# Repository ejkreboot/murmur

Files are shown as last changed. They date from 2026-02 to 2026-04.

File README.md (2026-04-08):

# Murmur

An audio "casette" player for the 21st century.

---

## Philosophy

Most audio hardware today is optimized for connectivity. Bluetooth, WiFi, cloud sync, firmware updates, pairing modes, app dependencies. These features solve real problems, but they also introduce friction — dead batteries from background radios, pairing failures at the worst moments, apps that require accounts, devices that stop working when servers go away, constant distractions and potentials for invasion of privacy or other undesirable intrusions.

Murmur is a deliberate step in the other direction. It plays audio files from a microSD card through a 3.5mm jack. That's the whole product. No wireless radios in use, no companion app, no account required. You put files on a card and press play.

Future revisions may (or may not) add internet and bluetooth features if they "just work" and maintain the Murmur ethos. 

The name comes from the idea that good audio gear should be unobtrusive. It should murmur in the background of your life, not demand attention.

---

## Hardware

**Microcontroller:** ESP32-S3-WROOM-1U (8MB flash)  
**DAC / Headphone driver:** Texas Instruments TAD5242  
**Battery management:** Microchip MCP73871  
**Storage:** MicroSD (via USB-C when connected to a computer)  
**Motion sensor:** ST LIS3DH (3-axis accelerometer)  
**Charging / Data:** USB-C  
**Output:** 3.5mm stereo headphone jack (PJ-327C-4A)

The ESP32-S3 was chosen for its capable USB peripheral support and audio I2S interface, not its wireless features. The TAD5242 handles D/A conversion and drives headphones directly. The MCP73871 manages single-cell Li-Ion/LiPo charging with thermistor-based temperature protection.

---

## User's Manual

For features, usage instructions, button controls, and audiobook support, see the **[Murmur User's Manual](https://ejkreboot.github.io/murmur/murmur_manual.html)**.

---

## Repository Contents

```
BOM.csv          — Full bill of materials with JLCPCB part numbers
docs/            — User's manual and supporting images
gerbers/         — Fabrication files (Gerber + drill) ready for PCB manufacture
firmware/murmur/ — Arduino sketch and source for the ESP32-S3
firmware/tools/  — Utilities (logo bitmap converter)
images/          — PCB renders, schematics, logos, and 3D model
Models/          — 3D-printable enclosure and button cap files (.3mf, .step)
```

---

## Firmware

The firmware lives in `firmware/murmur/` and is an Arduino sketch targeting the **ESP32-S3-WROOM-1U**. It uses the [Arduino AudioTools](https://github.com/pschatzmann/arduino-audio-tools) library with the Helix MP3 decoder.

### Building

1. Install the [Arduino IDE](https://www.arduino.cc/en/software) (or PlatformIO) with ESP32-S3 board support.
2. Install the required libraries: **Arduino AudioTools**, **Adafruit SSD1306**, **Adafruit LIS3DH**.
3. Open `firmware/murmur/murmur.ino`.
4. Select the **ESP32S3 Dev Module** board and configure: 8 MB flash, USB CDC on boot enabled.
5. Upload.

### Architecture

The firmware is modular and class-based:

| Module | Responsibility |
|---|---|
| `murmur.ino` | App state machine, NVS persistence, sleep/wake, main loop |
| `AudioPlayer` | MP3 decode, I2S output, EQ, volume, track/folder navigation |
| `ButtonManager` | 5-button debounce FSM with tap-defer and long-press detection |
| `DisplayManager` | OLED screens: track, settings menu, playlist, chapters, battery |
| `AccelManager` | LIS3DH flat-detect for display sleep/wake |
| `ID3Parser` | ID3v2 tag parsing: genre, chapters, MP3 frame header |
| `config.h` | Pin definitions, mode enums, tuning constants |

---

## Building One

The gerbers are in `gerbers/` and the BOM references JLCPCB part numbers, so ordering a board through JLCPCB (or any compatible fab) should be straightforward. The BOM includes all SMD components; assembly is possible by hand but a stencil is recommended given the QFN and LGA packages.

3D-printable enclosure and button cap models are in `Models/`.

---

## Contributing

This project is open source under the CERN-OHL-S-2.0 license. Improvements and modifications encouraged. Issues and pull requests are welcome.

---

## License

CERN-OHL-S-2.0

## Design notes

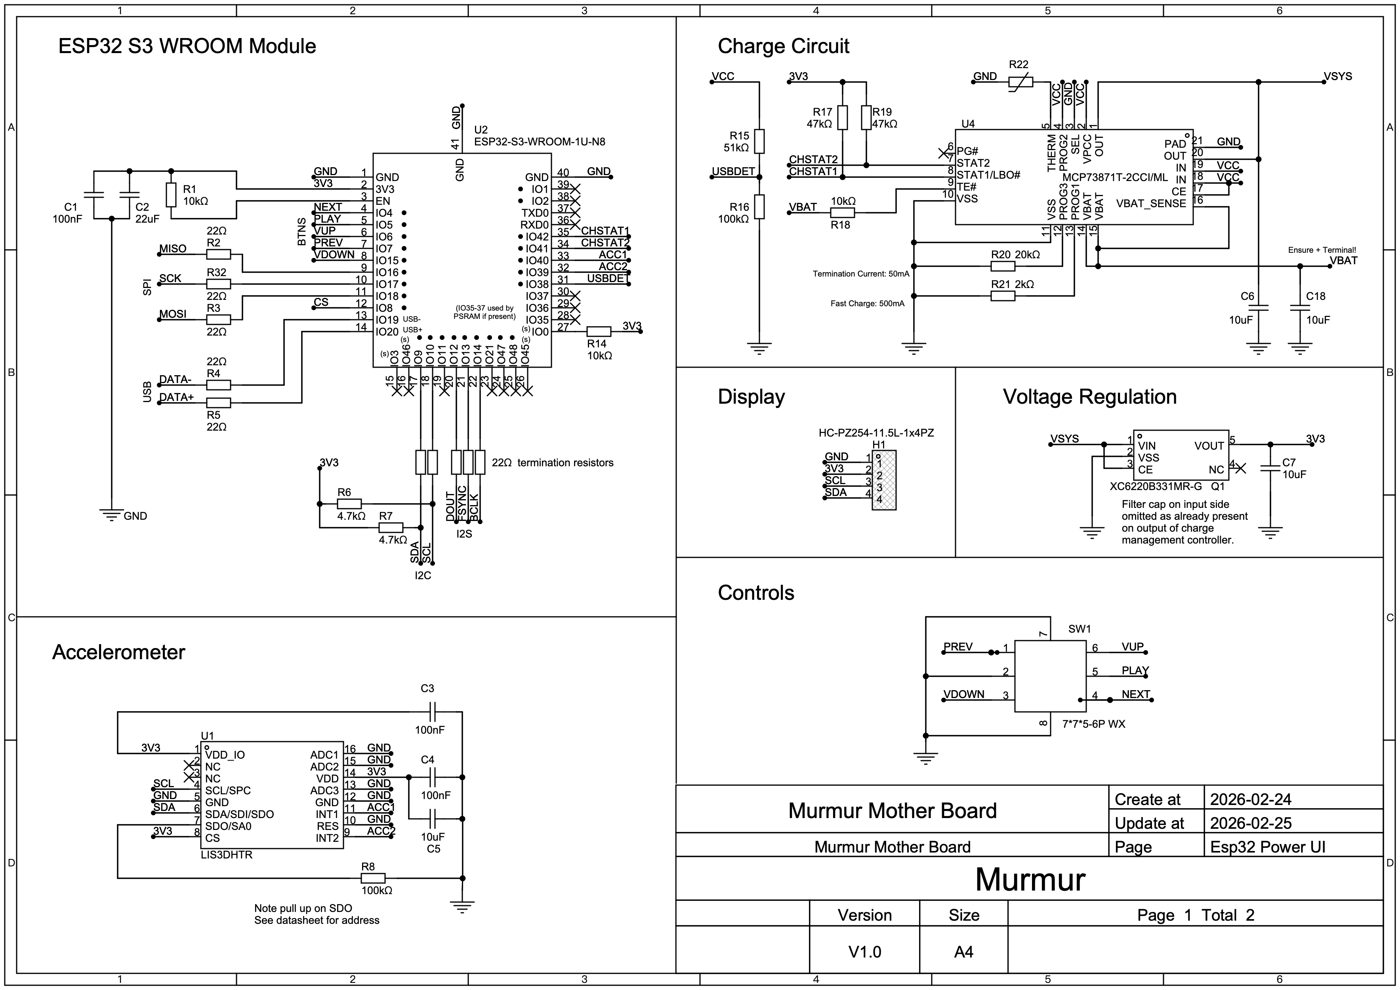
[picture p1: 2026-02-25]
images/SCH_Murmur Mother Board_1-Esp32 Power UI_2026-02-25.png

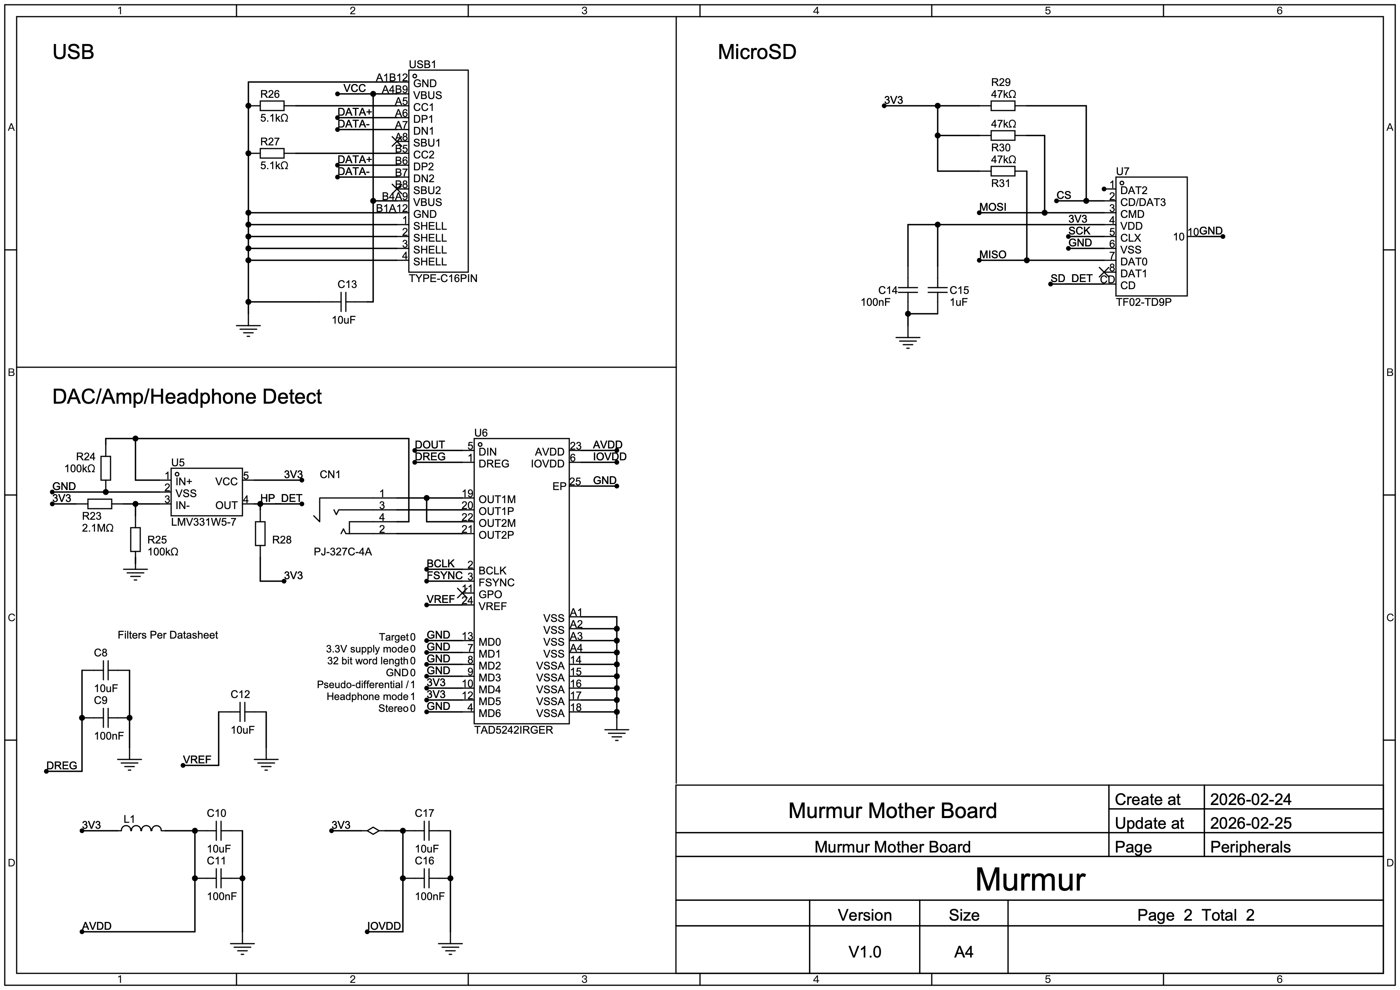
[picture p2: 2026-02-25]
images/SCH_Murmur Mother Board_2-Peripherals_2026-02-25.png

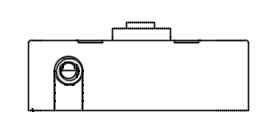
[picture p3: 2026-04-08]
docs/images/Drawing1.png

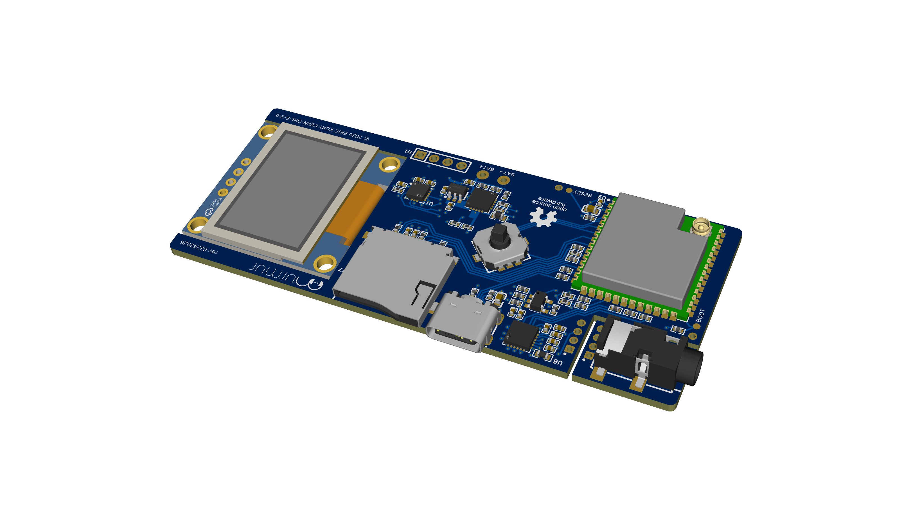
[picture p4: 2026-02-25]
images/PCB_3D.png

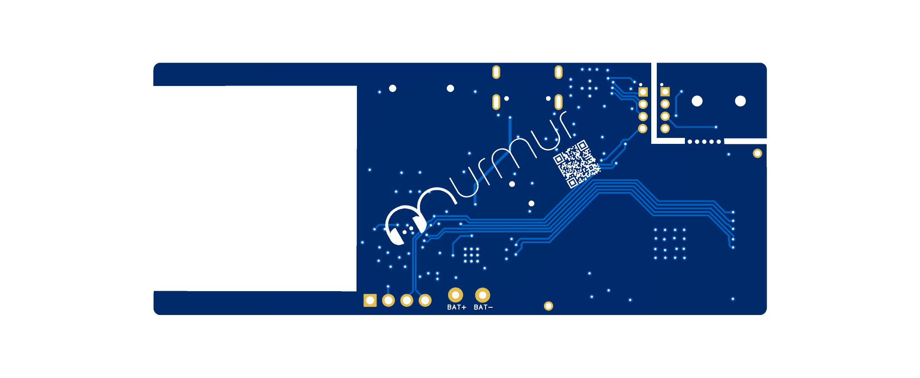
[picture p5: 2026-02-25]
images/PCB_2D_bottom.png

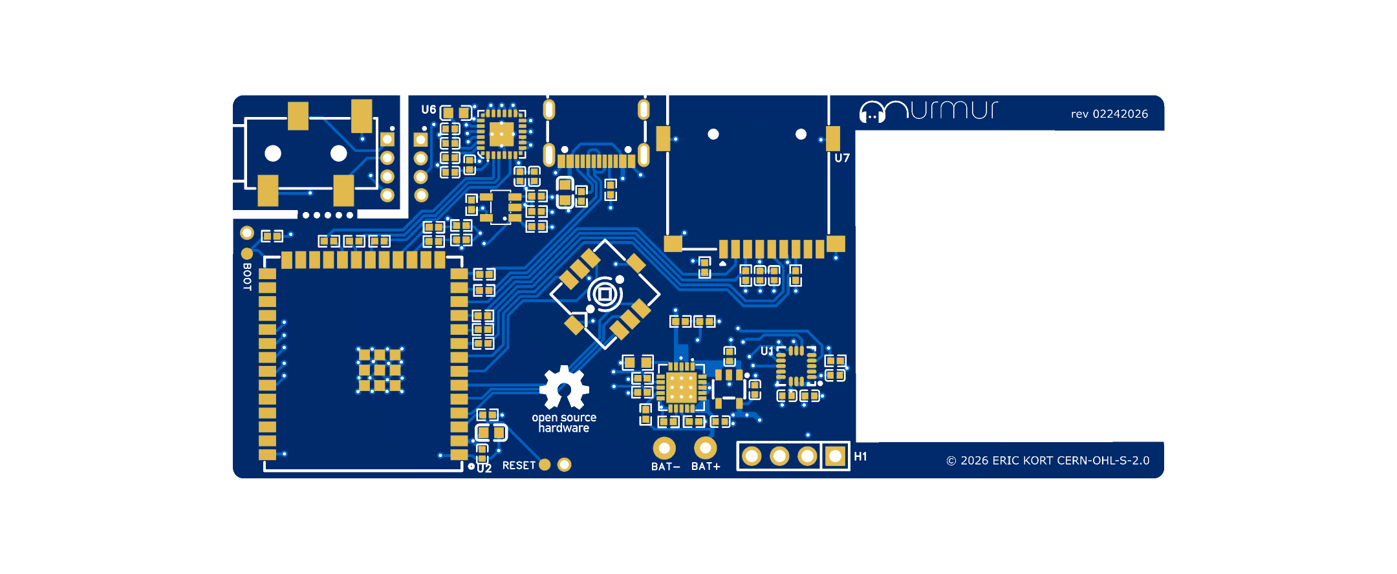
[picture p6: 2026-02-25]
images/PCB_2D_top.png

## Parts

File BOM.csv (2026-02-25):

No. | Quantity | Comment | Designator | Footprint | Value | Manufacturer Part | Manufacturer | Supplier Part | Name | Device | JLCPCB Price | Primary Category | Secondary Category | Datasheet
1 | 7 | 100nF | C1,C3,C4,C9,C11,C14,C16 | C0402 | 100nF | CL05B104KO5NNNC | SAMSUNG(三星) | C1525 | 100nF | CL05B104KO5NNNC | 0.0002 |  |  | https://item.szlcsc.com/datasheet/CL05B104KO5NNNC/1877.html
2 | 1 | 22uF | C2 | C0603 | 22uF | CL10A226MQ8NRNC | SAMSUNG(三星) | C59461 | 22uF | CL10A226MQ8NRNC | 0.0014 |  |  | https://item.szlcsc.com/datasheet/CL10A226MQ8NRNC/60514.html
3 | 8 | 10uF | C5,C6,C7,C8,C10,C12,C17,C18 | C0402 | 10uF | CL05A106MQ5NUNC | SAMSUNG(三星) | C15525 | 10uF | CL05A106MQ5NUNC | 0.0009 |  |  | https://item.szlcsc.com/datasheet/CL05A106MQ5NUNC/16204.html
4 | 1 | 10uF | C13 | C0603 | 10uF | CL10A106MA8NRNC | SAMSUNG(三星) | C96446 | 10uF | CL10A106MA8NRNC | 0.0026 |  |  | https://item.szlcsc.com/datasheet/CL10A106MA8NRNC/97651.html
5 | 1 | 1uF | C15 | C0402 | 1uF | CL05A105KA5NQNC | SAMSUNG(三星) | C52923 | 1uF | CL05A105KA5NQNC | 0.0005 | Capacitors | Multilayer Ceramic Capacitors MLCC - SMD/SMT | https://item.szlcsc.com/datasheet/CL05A105KA5NQNC/53938.html
6 | 1 | PJ-327C-4A | CN1 | AUDIO-SMD_PJ-327C-4A |  | PJ-327C-4A | 韩国韩荣 | C145813 | PJ-327C-4A | PJ-327C-4A | 0.0207 |  |  | https://item.szlcsc.com/datasheet/PJ-327C-4A/157145.html
7 | 1 | GZ1608D601TF | L1 | L0603 |  | GZ1608D601TF | Sunlord(顺络) | C1002 | GZ1608D601TF | GZ1608D601TF | 0.0019 | Filters | Ferrite Beads | https://item.szlcsc.com/datasheet/GZ1608D601TF/1354.html
8 | 1 | XC6220B331MR-G | Q1 | SOT-25_L3.0-W1.6-P0.95-LS2.8-TL |  | XC6220B331MR-G | TOREX(特瑞仕) | C86534 | XC6220B331MR-G | XC6220B331MR-G | 0.0699 |  |  | https://item.szlcsc.com/datasheet/XC6220B331MR-G/87711.html
9 | 3 | 10kΩ | R1,R14,R18 | R0402 | 10kΩ | 0402WGF1002TCE | UNI-ROYAL(厚声) | C25744 | 10kΩ | 0402WGF1002TCE | 0.0002 |  |  | https://item.szlcsc.com/datasheet/0402WGF1002TCE/26487.html
10 | 10 | 22Ω | R2,R3,R4,R5,R9,R10,R11,R12,R13,R32 | R0402 | 22Ω | 0402WGF220JTCE | UNI-ROYAL(厚声) | C25092 | 22Ω | 0402WGF220JTCE | 0.0002 |  |  | https://atta.szlcsc.com/upload/public/pdf/source/20200306/C422600_1E6D84923E4A46A82E41ADD87F860B5C.pdf
11 | 2 | 4.7kΩ | R6,R7 | R0402 | 4.7kΩ | 0402WGF4701TCE | UNI-ROYAL(厚声) | C25900 | 4.7kΩ | 0402WGF4701TCE | 0.0002 |  |  | https://item.szlcsc.com/datasheet/0402WGF4701TCE/26643.html
12 | 5 | 100kΩ | R8,R16,R24,R25,R28 | R0402 | 100kΩ | 0402WGF1003TCE | UNI-ROYAL(厚声) | C25741 | 100kΩ | 0402WGF1003TCE | 0.0002 |  |  | https://atta.szlcsc.com/upload/public/pdf/source/20180314/0E2614623E0414D50D3004040B0D85FE.pdf,https://item.szlcsc.com/datasheet/0402WGF1003TCE/26484.html
13 | 1 | 51kΩ | R15 | R0402 | 51kΩ | 0402WGF5102TCE | UNI-ROYAL(厚声) | C25794 | 51kΩ | 0402WGF5102TCE | 0.0002 |  |  | https://atta.szlcsc.com/upload/public/pdf/source/20200306/C422600_1E6D84923E4A46A82E41ADD87F860B5C.pdf
14 | 5 | 47kΩ | R17,R19,R29,R30,R31 | R0402 | 47kΩ | 0402WGF4702TCE | UNI-ROYAL(厚声) | C25792 | 47kΩ | 0402WGF4702TCE | 0.0002 |  |  | https://item.szlcsc.com/datasheet/0402WGF4702TCE/26535.html
15 | 1 | 20kΩ | R20 | R0402 | 20kΩ | 0402WGF2002TCE | UNI-ROYAL(厚声) | C25765 | 20kΩ | 0402WGF2002TCE | 0.0002 |  |  | https://atta.szlcsc.com/upload/public/pdf/source/20200306/C422600_1E6D84923E4A46A82E41ADD87F860B5C.pdf
16 | 1 | 2kΩ | R21 | R0402 | 2kΩ | 0402WGF2001TCE | UNI-ROYAL(厚声) | C4109 | 2kΩ | 0402WGF2001TCE | 0.0002 |  |  | https://atta.szlcsc.com/upload/public/pdf/source/20200306/C422600_1E6D84923E4A46A82E41ADD87F860B5C.pdf
17 | 1 | KNTC0603/10KJ3950 | R22 | R0603 |  | KNTC0603/10KJ3950 | KUU | C20612968 | KNTC0603/10KJ3950 | KNTC0603/10KJ3950 | 0.0035 | Sensors | NTC Thermistors | https://item.szlcsc.com/datasheet/KNTC0603%252F10KJ3950/21973016.html
18 | 1 | 2.1MΩ | R23 | R0402 | 2.1MΩ | RC0402FR-072M1L | YAGEO(国巨) | C477638 | 2.1MΩ | RC0402FR-072M1L | 0.0001 |  |  | https://atta.szlcsc.com/upload/public/pdf/source/20200715/C477638_CABFCAEDA01CE96BF50AD84070FAC134.pdf
19 | 2 | 5.1kΩ | R26,R27 | R0402 | 5.1kΩ | 0402WGF5101TCE | UNI-ROYAL(厚声) | C25905 | 5.1kΩ | 0402WGF5101TCE | 0.0002 |  |  | https://item.szlcsc.com/datasheet/0402WGF5101TCE/26648.html
20 | 1 | 7*7*5-6P WX | SW1 | SW-SMD_6P-L7.0-W7.0-P1.40-LS7.4-TL |  | 7*7*5-6P WX | SHOU HAN(首韩) | C2858286 | 7*7*5-6P WX | 7*7*5-6P WX | 0.0424 |  |  | https://atta.szlcsc.com/upload/public/pdf/source/20210806/C2858286_484786EF684589807E899A8060F52B6F.pdf
21 | 1 | LIS3DHTR | U1 | LGA-16_L3.0-W3.0-P0.50-TL |  | LIS3DHTR | ST(意法半导体) | C15134 | LIS3DHTR | LIS3DHTR | 0.115 | Sensors | Accelerometers | https://item.szlcsc.com/datasheet/LIS3DHTR/15808.html
22 | 1 | ESP32-S3-WROOM-1U-N8 | U2 | WIRELM-SMD_ESP32-S3-WROOM-1U |  | ESP32-S3-WROOM-1U-N8 | ESPRESSIF(乐鑫) | C2980297 | ESP32-S3-WROOM-1U-N8 | ESP32-S3-WROOM-1U-N8 | 0.726 | IoT/Communication Modules | WiFi Modules | https://item.szlcsc.com/datasheet/ESP32-S3-WROOM-1U-N8/3401549.html
23 | 1 | MCP73871T-2CCI/ML | U4 | QFN-20_L4.0-W4.0-P0.5-BL-EP |  | MCP73871T-2CCI/ML | MICROCHIP(美国微芯) | C511310 | MCP73871T-2CCI/ML | MCP73871T-2CCI/ML | 0.306 | Power Management (PMIC) | Battery Management | https://item.szlcsc.com/datasheet/MCP73871T-2CCI%252FML/525757.html
24 | 1 | LMV331W5-7 | U5 | SOT-23-5_L3.0-W1.7-P0.95-LS2.8-BR |  | LMV331W5-7 | DIODES(美台) | C107643 | LMV331W5-7 | LMV331W5-7 | 0.0172 | Amplifiers/Comparators | Comparators | https://item.szlcsc.com/datasheet/LMV331W5-7/108862.html
25 | 1 | TAD5242IRGER | U6 | VQFN-24_L4.0-W4.0-P0.50-TL_RGE0024R |  | TAD5242IRGER | TI(德州仪器) | C42414591 | TAD5242IRGER | TAD5242IRGER_C42414591 | 0.9899 | Interface | Audio Interface ICs | https://item.szlcsc.com/datasheet/TAD5242IRGER/44407216.html
26 | 1 | TF02-TD9P | U7 | CONN-SMD_TF02-TD9P |  | TF02-TD9P | BXCONN(宝讯) | C36936583 | TF02-TD9P | TF02-TD9P | 0.014 |  |  | https://item.szlcsc.com/datasheet/TF02-TD9P/38663659.html
27 | 1 | TYPE-C16PIN | USB1 | USB-C-SMD_TYPE-C16PIN |  | TYPE-C16PIN | SHOU HAN(首韩) | C393939 | TYPE-C16PIN | TYPE-C16PIN | 0.0103 | Connectors | USB Connectors | https://item.szlcsc.com/datasheet/TYPE-C16PIN/372551.html

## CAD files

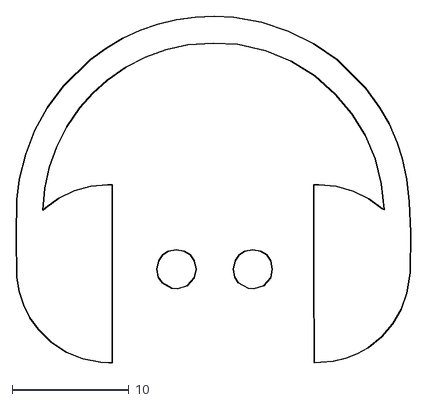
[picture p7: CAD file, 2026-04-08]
images/icon.dxf
33.8 x 29.7

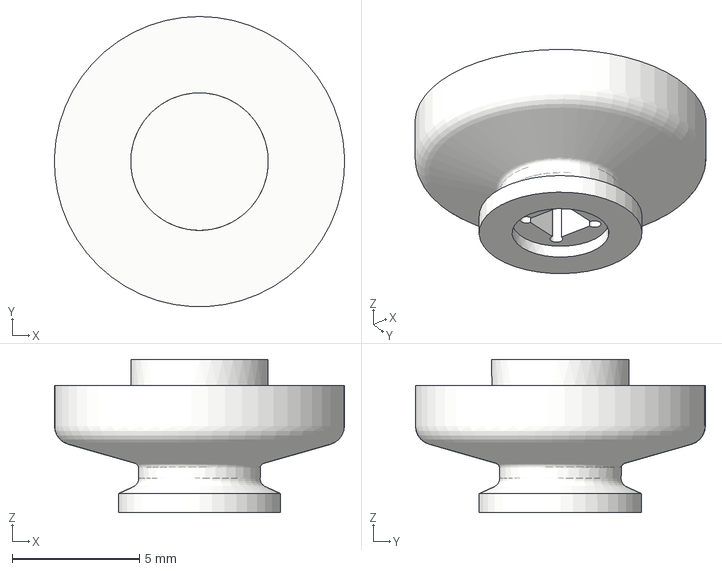
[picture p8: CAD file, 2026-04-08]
Models/Enclosure Final Button.3mf
11.4 x 11.4 x 6.03 mm

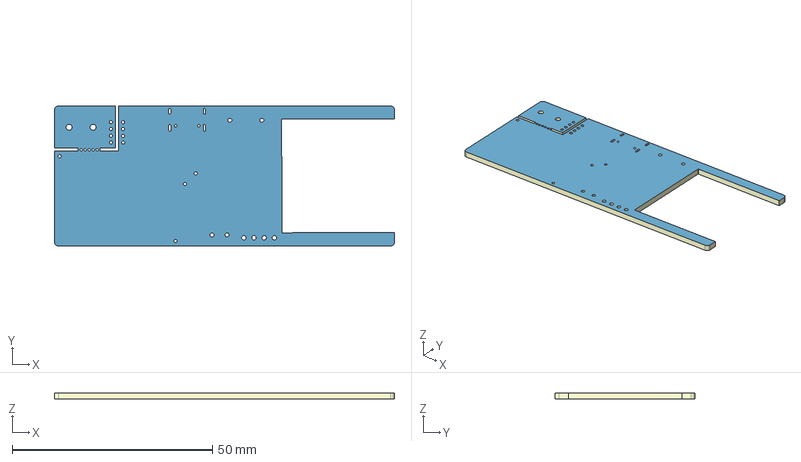
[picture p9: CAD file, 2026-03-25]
images/3D_PCB1_2026-03-15_Board_Only.step
85.0 x 35.0 x 1.59 mm
Board~DDom
TopCopper~DDom
BottomCopper~DDom
TopFpcStiffener~DDom
BottomFpcStiffener~DDom

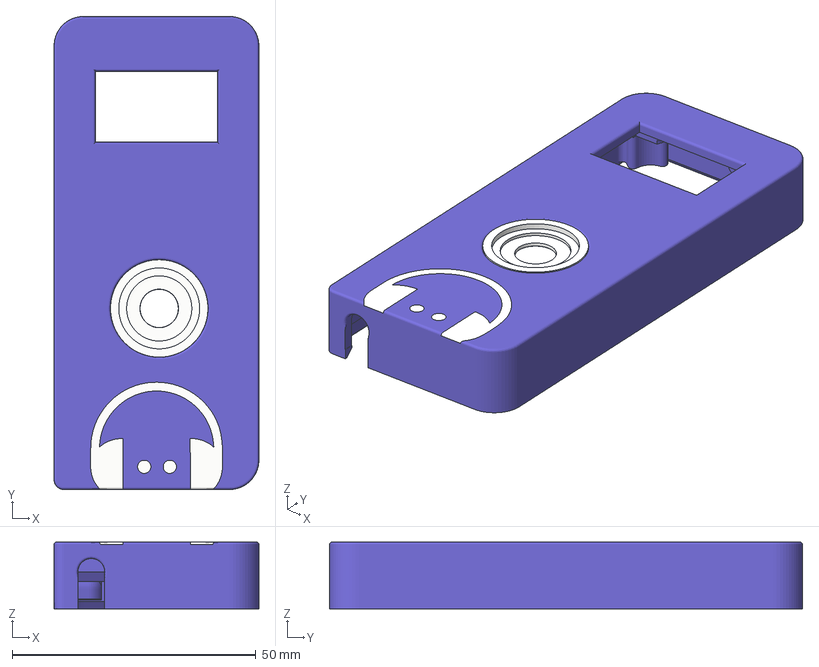
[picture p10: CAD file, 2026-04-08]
Models/Enclosure Final Top.3mf
42.0 x 97.0 x 13.7 mm

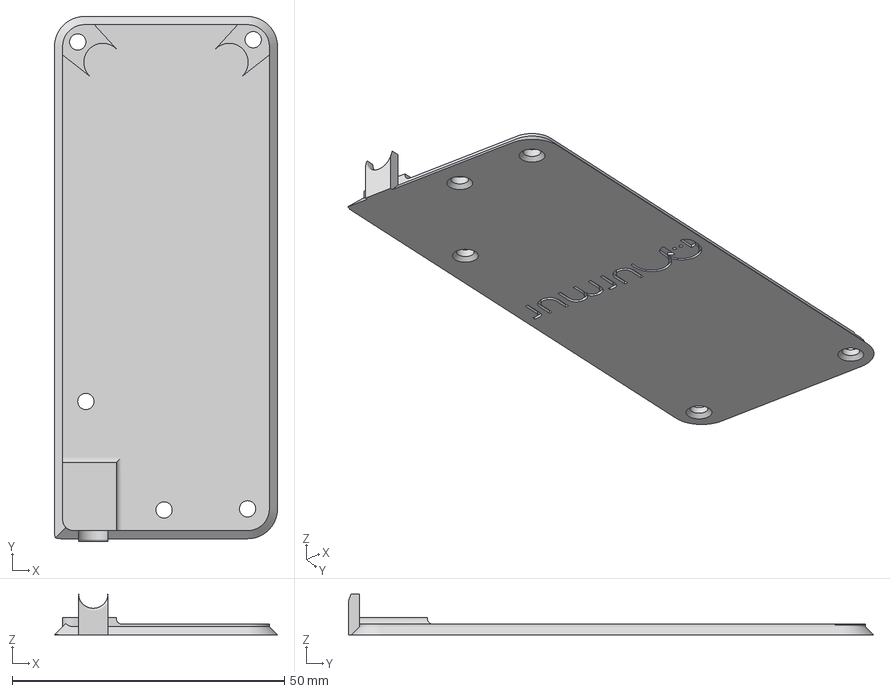
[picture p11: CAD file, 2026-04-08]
Models/Enclosure Final Bottom.3mf
41.0 x 96.5 x 7.50 mm

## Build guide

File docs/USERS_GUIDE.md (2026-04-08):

# Murmur User's Guide

Murmur is a simple, distraction-free MP3 player. No apps, no accounts, no wireless — just your music on a microSD card and a 3.5mm headphone jack.

---

## Getting Started

### 1. Prepare Your SD Card

Format a microSD card as **FAT32**. Copy your MP3 files to the root of the card, or organize them into folders.

```
SD Card
├── song1.mp3
├── song2.mp3
├── Road Trip/
│   ├── track1.mp3
│   └── track2.mp3
└── Chill/
    ├── intro.mp3
    └── sunset.mp3
```

- **Root-level files** are part of the "All Songs" playlist.
- **Folders** become selectable playlists. Each folder's MP3 files are sorted alphabetically.
- Files and folders are sorted alphabetically (case-insensitive).

### 2. Insert the Card & Power On

Slide the microSD card into the Murmur's card slot. Press the **Play** button. The OLED display will show a startup logo, then begin playback from the first track.

### 3. Plug In Headphones

Connect headphones or a speaker to the **3.5mm headphone jack**.

---

## Button Controls

Murmur has five buttons: **Play**, **Next**, **Prev** (Back), **Vol Up**, and **Vol Down**.

| Button | Short Press | Long Press (hold) |
|---|---|---|
| **Play** | Play / Pause | Hold 3 seconds → Power off (deep sleep) |
| **Play × 2** (double-tap) | Open / close Settings menu | — |
| **Next** | Skip to next track | Open Chapter menu (audiobooks only) |
| **Prev** | Go to previous track | Open Playlist menu |
| **Vol Up** | Increase volume | Auto-repeats while held |
| **Vol Down** | Decrease volume | Auto-repeats while held |

---

## The Display

The OLED screen shows different information depending on what you're doing:

### Now Playing Screen

When music is playing, the display shows:
- **Play/pause icon** — indicates current playback state
- **Track counter** — e.g. "3/12" (track 3 of 12)
- **Volume bar** — visual indicator of the current volume level
- **Track title** — scrolls automatically if it's too long to fit on screen
- **Playlist or chapter name** — shown at the bottom (the active folder name, or the current chapter name for audiobooks)

### Volume Overlay

When you adjust the volume, a volume bar briefly appears on screen showing the new level.

---

## Playlists (Folders)

Murmur treats each folder on the SD card as a playlist.

### Browsing Playlists

1. **Long-press Prev** to open the Playlist menu.
2. Use **Vol Up / Vol Down** to scroll through the list.
3. The first option is always **"All Songs"**, which plays every MP3 on the card.
4. Press **Play** to select a playlist and start playback.
5. Press **Prev** to go back without changing the playlist.

---

## Settings Menu

**Double-tap Play** to open the Settings menu. Double-tap again (or select "Exit") to return to the Now Playing screen.

Use **Vol Up / Vol Down** to move between settings, and **Play** to cycle through options:

### Equalizer (EQ)

Three presets that shape the sound:
- **Loud** — boosted presence and punch
- **Bass Boost** — enhanced low-end
- **Flat** — no EQ applied (default)

### Sleep Timer

Automatically pauses playback after a set time — great for falling asleep to music or audiobooks:
- **Off** (default)
- **30 min**
- **60 min**

The timer resets each time you power on.

### Repeat Mode

Controls what happens when the current track or playlist ends:
- **All** — loop the entire playlist (default)
- **One** — repeat the current track
- **Off** — stop at the end of the playlist

---

## Audiobooks

Murmur has built-in audiobook support with bookmarking and chapter navigation.

### How Murmur Detects Audiobooks

An MP3 file is treated as an audiobook if its **ID3v2 genre tag** contains the word "Audiobook". You can set this tag using any music tagging tool (e.g. Mp3tag, MusicBrainz Picard, or Kid3).

### Bookmarks

Murmur **automatically saves your position** in an audiobook when you:
- Pause playback
- Switch to a different playlist
- Power off or the device goes to sleep

When you power on again, playback **resumes exactly where you left off**.

### Chapter Navigation

If your audiobook file contains **ID3v2 CHAP frames** (embedded chapter markers):

1. **Long-press Next** to open the Chapter menu.
2. Use **Vol Up / Vol Down** to scroll through chapters. The current chapter is highlighted.
3. Press **Play** to jump to the selected chapter.
4. Press **Next** or **Prev** to close the menu without jumping.

The current chapter name is displayed at the bottom of the Now Playing screen and updates automatically as playback progresses.

---

## Power Management

### Deep Sleep (Power Off)

**Hold the Play button for 3 seconds.** Murmur will display a power-off message, save your settings and audiobook bookmark, then enter deep sleep with minimal power draw.

To wake up, **press the Play button**. The device fully restarts and restores your last settings.

### Display Auto-Sleep

Murmur uses a built-in motion sensor. When you **set the device down flat for 2 seconds**, the display automatically turns off to save power. **Pick it up** and the display turns back on immediately. Audio playback continues uninterrupted in either case.

### Low Battery

When the battery is low, Murmur will:
1. Save your audiobook bookmark and settings.
2. Stop playback.
3. Show a **battery icon** on the display.

Plug in a USB-C cable to charge. The display will show a **lightning bolt** when charging. Once the battery recovers (or USB power is connected), the device automatically restarts.

---

## Charging

Connect a **USB-C cable** to charge the battery. You can also use the USB-C connection to **load files onto the microSD card** from a computer without removing the card.

---

## SD Card Tips

- **Supported format:** MP3 files only.
- **Card format:** FAT32.
- **File organization:** Files in the root and in one level of subfolders are recognized. Deeply nested folders are not scanned.
- **Naming:** Track order is alphabetical. Prefix filenames with numbers (e.g. `01 - Intro.mp3`, `02 - Chapter One.mp3`) if you want a specific play order.
- **No SD card?** Murmur will display "No SD Card" and wait. Insert a card and it will automatically restart.
- **Card removed during playback?** Murmur detects this, displays "SD Removed", and waits for you to reinsert the card.

---

## Settings That Persist

The following settings are **saved across power cycles** — you don't need to reconfigure them each time:

- Volume level
- EQ preset
- Repeat mode
- Audiobook bookmark (track + position)

The sleep timer always resets to **Off** on each boot.

---

## Quick Reference

| Action | How |
|---|-----|
| Play / Pause | Press **Play** |
| Next track | Press **Next** |
| Previous track | Press **Prev** |
| Volume up/down | Press **Vol Up** / **Vol Down** |
| Open Settings | Double-tap **Play** |
| Open Playlists | Long-press **Prev** |
| Open Chapters | Long-press **Next** (audiobooks) |
| Power off | Hold **Play** for 3 seconds |
| Power on | Press **Play** |

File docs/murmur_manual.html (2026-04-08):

KORTECH MODEL MRM-1 · REV A

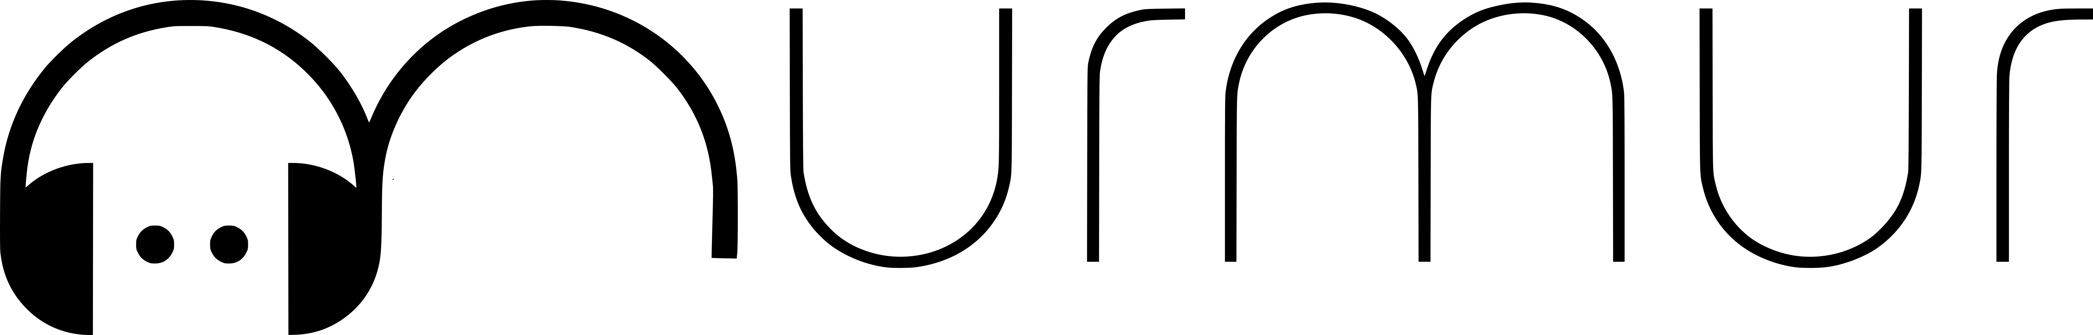
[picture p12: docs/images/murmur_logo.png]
Line drawing of the Murmur MRM-1 portable audio player


Portable Digital Audio Player
Owner's Manual

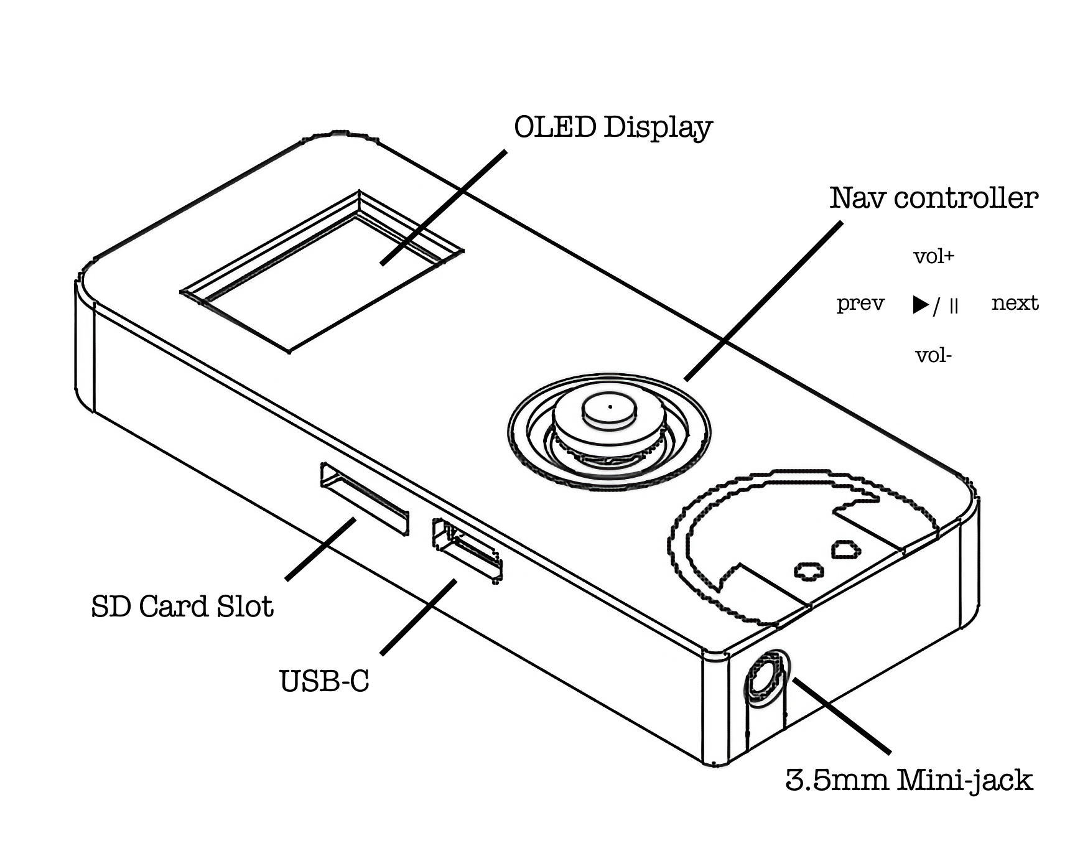
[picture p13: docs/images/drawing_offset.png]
Line drawing of the Murmur MRM-1 portable audio player


KORTECH PLEASE READ BEFORE OPERATING MRM1-OM-EN

CONTENTS PAGE 2

Thank you for "purchasing" the Murmur portable audio player.
This manual reviews the major features and use of your player.

01 | Getting Started / SD Card Setup | 3
02 | Basic Playback Operation | 4
03 | Playlists & Folder Navigation | 5
04 | Settings Menu (EQ / Timer / Repeat) | 6
05 | Audiobook Mode | 7
06 | Power Management & Charging | 8
07 | Specifications | 9

SAFETY NOTES

⚠ CAUTION Listening at high volumes can be damaging to your hearing.

NOTE

Specifications and features in this manual are subject to change without notice. For the latest information, visit github.com/ejkreboot/murmur/

KORTECH · MURMUR MRM-1 © KORTECH

02 · GETTING STARTED PAGE 3

# SD Card Setup

## Step 1 — Format the Card

Format a microSD card as FAT32 using your computer before first use. Murmur supports MP3 files only. Other audio formats will be ignored.

## Step 2 — Copy Your Music

Copy MP3 files to the card. Files can be placed at the root level or inside one level of folders. Deeply nested folders are not scanned.

SD CARD ROOT/
├── song1.mp3 ← part of "All Songs"
├── song2.mp3
├── Road Trip/ ← becomes a playlist
│ ├── 01-start.mp3
│ └── 02-highway.mp3
└── Chill/ ← another playlist
├── intro.mp3
└── sunset.mp3

TIP

To control play order, prefix filenames with numbers:
01 - Opening.mp3 02 - Chapter One.mp3
Files are sorted alphabetically within each folder.

## Step 3 — Insert Card & Power On

Insert the microSD card into the slot on the top edge of the unit (label facing up). Press the ▶/|| button (center press on the 5-way nav button). Murmur will display a startup logo and begin playback from the first track automatically.

## Step 4 — Connect Headphones

Plug headphones or a speaker into the 3.5mm jack on the bottom of the unit.

SD CARD TIPS

SITUATION | WHAT HAPPENS
No card inserted | Display shows "No SD Card". Murmur waits. Insert card to restart automatically.
Card removed during playback | Display shows "SD Removed". Murmur waits for card to be reinserted.
Unsupported files | Non-MP3 files are silently ignored. Only .mp3 files appear in playlists.

KORTECH · MURMUR MRM-1 4

03 · BASIC PLAYBACK PAGE 4

# Button Reference

BUTTON | SHORT PRESS | LONG PRESS / HOLD
▶/|| (center) | Play / Pause | Hold 3 sec → Power off
▶/|| ×2 | Open Settings menu | —
▶ NEXT | Skip to next track | Open Chapter menu (audiobooks only)
◀ PREV | Go to previous track | Open Playlist menu
▲ VOL UP | Increase volume | Auto-repeats while held
▼ VOL DOWN | Decrease volume | Auto-repeats while held

KORTECH · MURMUR MRM-1 5

04 · PLAYLISTS PAGE 5

# Folder = Playlist

Murmur treats each folder on the SD card as a separate playlist. The special "All Songs" playlist collects every MP3 on the card, including files at the root level.

## Browsing Playlists

1 Long-press ◀ PREV to open the Playlist menu.

2 Use ▲ VOL+ / ▼ VOL- to scroll through the list.

3 The first entry is always "All Songs."

4 Press ▶/|| to select a playlist and start playback immediately.

5 Press ◀ PREV to cancel and return without changing the playlist.

The highlighted row (shown brighter) is the currently selected item.

Scroll with ▲ / ▼

Confirm with ▶/||

Cancel with ◀ PREV

NOTE

Files and folders are sorted alphabetically (case-insensitive). Prefix folder names (e.g. 01-RoadTrip) to control their order in the menu.

KORTECH · MURMUR MRM-1 6

05 · SETTINGS MENU PAGE 6

Double-tap ▶/|| to open Settings. Double-tap again or select Exit to return.

Navigate with ▲ / ▼. Change values with ▶/||.

EQ PRESET

SETTING | DESCRIPTION
FLAT (default) | No equalization applied. Pure, unmodified output.
BASS BOOST | Enhanced low-end frequencies. Good for headphones with limited bass response.
LOUD | Boosted presence and punch. Suitable for noisy environments.

SLEEP TIMER

Automatically pauses playback after the selected time. Ideal for bedtime listening. Timer always resets to Off when Murmur powers on.

VALUE | BEHAVIOR
OFF (default) | No timer. Playback continues until manually paused or powered off.
30 MIN | Pauses playback 30 minutes after timer is set.
60 MIN | Pauses playback 60 minutes after timer is set.

REPEAT MODE

VALUE | BEHAVIOR
ALL (default) | Loops the entire playlist continuously.
ONE | Repeats the current track indefinitely.
OFF | Stops playback when the playlist ends.

KORTECH · MURMUR MRM-1 7

06 · AUDIOBOOK MODE PAGE 7

# Audiobook Automatic Detection

Murmur automatically detects audiobooks by reading the ID3v2 Genre tag. If the genre field of an MP3 contains the word "Audiobook", the file is treated as an audiobook with bookmark and chapter support.

# Automatic Bookmarking

Murmur saves your exact playback position automatically. You will never lose your place.

ACTION | BOOKMARK IS SAVED
Pause playback | ✓ Immediately
Switch playlist | ✓ Before switching
Power off (hold Play) | ✓ Before entering sleep
Battery depleted | ✓ Before shutting down

When you power on again, Murmur resumes exactly where you left off.

# Chapter Navigation

If your audiobook MP3 contains ID3v2 CHAP frames (embedded chapter markers), Murmur can jump directly to any chapter.

1 Long-press ▶ NEXT to open the Chapter menu.

2 Use ▲ / ▼ to scroll. The current chapter is highlighted.

3 Press ▶/|| to jump to the selected chapter.

4 Press ▶ NEXT or ◀ PREV to close menu without jumping.

KORTECH · MURMUR MRM-1 8

07 · POWER MANAGEMENT PAGE 8

# Powering On & Off

ACTION | HOW
Power On | Press ▶/|| briefly. Device starts up and restores last settings.
Power Off | Hold ▶/|| for 3 seconds. Display shows power-off message, settings are saved, then device enters deep sleep.

DEEP SLEEP

In deep sleep, battery draw is minimal. Volume, EQ, Repeat mode, and your audiobook bookmark are all preserved. Press ▶/|| to wake.

# Display Auto-Sleep

Murmur has a built-in motion sensor. When the device is set down flat for 2 seconds, the display automatically turns off. Pick it up and the display turns back on immediately. Audio playback is unaffected in either state.

# Charging

## Charging via USB-C

Connect a USB-C cable to charge the internal battery. A lightning bolt icon is displayed while charging.

# Low Battery

STEP | ACTION
1 | Audiobook bookmark and settings are saved automatically.
2 | Playback stops.
3 | A battery icon appears on the display.
4 | Connect USB-C to charge. Device auto-restarts when power is restored.

KORTECH · MURMUR MRM-1 9

10 · SPECIFICATIONS PAGE 9

# Technical Specifications

PlatformESP32-S3

Audio OutputTAD5242 DAC

Jack3.5mm stereo

DisplaySSD1306 OLED

StoragemicroSD (FAT32)

Audio FormatMP3

MotionLIS3DH accel.

ChargingUSB-C (MCP73871)

PCB4-layer custom

Enclosure3D-printed ASA

Open SourceYes (OSHWLab)

# Troubleshooting

SYMPTOM | CHECK
No sound | Is the volume above 0? Are headphones fully inserted?
"No SD Card" displayed | Insert card with label facing up. Ensure it is FAT32 formatted.
Tracks not appearing | Only MP3 files are supported. Folders are only scanned one level deep.
Wrong play order | Prefix filenames with numbers: 01-name.mp3
Audiobook not resuming | Ensure genre tag is set to Audiobook. Bookmark saves on pause/power-off.
Display stays off | Pick up device. Display auto-sleeps when flat but resumes on motion.
Won't power on | Battery may be depleted. Connect USB-C and wait for auto-restart.

OPEN SOURCE

Murmur is an open-source hardware project.
Schematics, firmware, and enclosure files available at:
github.com/ejkreboot/murmur/
Submitted to OSHWLab Stars Program

KORTECH

MAKER ELECTRONICS

Model: MRM-1

Manual: MRM1-OM-EN Rev A

Printed in USA

KORTECH · MURMUR MRM-1 12

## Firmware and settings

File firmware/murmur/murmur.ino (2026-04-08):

//  murmur.ino
//  Murmur audio player — KorTech
//  Minimal first pass: SD track list → playback → OLED display → volume control

#include <Arduino.h>
#include <Preferences.h>
#include <esp_sleep.h>
#include <driver/rtc_io.h>
#include <WiFi.h>
#include "AudioTools.h"
#include "AudioTools/AudioCodecs/CodecMP3Helix.h"

#include "config.h"
#include "ButtonManager.h"
#include "DisplayManager.h"
#include "AudioPlayer.h"
#include "AccelManager.h"

// ── Module instances ──────────────────────────────────────────────────────────
ButtonManager buttons(BTN_NEXT, BTN_PREV, BTN_VUP, BTN_VDOWN, BTN_PLAY);
DisplayManager display(SDA_PIN, SCL_PIN, OLED_ADDR, SCREEN_WIDTH, SCREEN_HEIGHT);
MurmurPlayer  player(SD_CS, SD_SCK, SD_MISO, SD_MOSI, I2S_BCLK, I2S_FSYNC, I2S_DOUT);
AccelManager  accel(LIS3DH_INT1, LIS3DH_INT2);

// ── Preferences (NVS) ────────────────────────────────────────────────────────
static Preferences prefs;
static constexpr char  PREF_NS[]      = "murmur";
static constexpr char  PREF_VOL[]     = "volume";
static constexpr char  PREF_EQ[]      = "eq";
static constexpr char  PREF_TIMER[]   = "timer";
static constexpr char  PREF_REPEAT[]  = "repeat";
static constexpr char  PREF_BM_PATH[] = "bm_path";  // audiobook bookmark: track path
static constexpr char  PREF_BM_POS[]  = "bm_pos";   // audiobook bookmark: byte offset
static constexpr float DEFAULT_VOLUME = 0.3f;   // safe default on first boot

static constexpr float VOL_STEP = 0.05f;

// ── App state ─────────────────────────────────────────────────────────────────
enum class AppState { PLAYING, IN_MENU, IN_PLAYLIST, IN_CHAPTERS };
static AppState   appState        = AppState::PLAYING;
static int        menuItem        = 0;           // 0=EQ, 1=Timer, 2=Repeat
static int        playlistSel     = 0;           // 0=All Songs, 1..N=folder index
static int        chapterSel      = 0;           // chapter menu selection index
static EqMode     eqMode          = EqMode::FLAT;
static TimerMode  timerMode       = TimerMode::OFF;
static RepeatMode repeatMode      = RepeatMode::ALL;
static uint32_t   timerStartMs    = 0;         // millis() when timer was armed (0 = inactive)

// ── Display sleep state ──────────────────────────────────────────────────────────
static bool     displaySleeping     = false;
static uint32_t lastOrientPollMs    = 0;
static constexpr uint32_t ORIENT_POLL_MS = 100;  // poll rate while display is off
// ── Low battery state ─────────────────────────────────────────────────────────────────
static bool     lowBattery      = false;
static int      lastChapterIdx  = -1;            // for detecting chapter boundary crossings
static uint32_t lastChapterCheckMs = 0;
static constexpr uint32_t CHAPTER_CHECK_MS = 1000;  // chapter update poll interval
// ── Deferred NVS writes ─────────────────────────────────────────────────────────────
static bool     nvsDirtyVolume    = false;
static bool     nvsDirtyEq        = false;
static bool     nvsDirtyTimer     = false;
static bool     nvsDirtyRepeat    = false;
static bool     nvsDirtyBookmark  = false;
static uint32_t nvsLastDirtyMs    = 0;            // millis() of last dirty flag set
static constexpr uint32_t NVS_FLUSH_DELAY_MS = 2000;  // flush after 2 s of quiet
// ── Display throttle ─────────────────────────────────────────────────────────────────
static uint32_t lastDisplayMs     = 0;
static constexpr uint32_t DISPLAY_MIN_MS = 30;    // minimum ms between full redraws
// ── Helpers ───────────────────────────────────────────────────────────────────
void refreshTrackDisplay() {
  uint32_t now = millis();
  if (now - lastDisplayMs < DISPLAY_MIN_MS) return;  // throttle redraws
  lastDisplayMs = now;
  String chapterName = player.isAudiobook() ? player.getChapterName() : "";
  display.showTrack(player.currentName(),
                    player.currentIndex(),
                    player.trackCount(),
                    player.isPlaying(),
                    player.getPlaylistName(),
                    chapterName);
  lastChapterIdx = player.getCurrentChapterIndex();
}

void adjustVolume(float delta) {
  float v = player.getVolume() + delta;
  player.setVolume(v);
  nvsDirtyVolume = true;
  nvsLastDirtyMs = millis();
  display.showVolume(player.getVolume());
}

// Mark audiobook bookmark dirty (flushed by nvsFlush).
void saveBookmark() {
  if (!player.isAudiobook() || !player.isPlaying()) return;
  nvsDirtyBookmark = true;
  nvsLastDirtyMs   = millis();
}

// Write all dirty NVS values to flash.  Called after a quiet period or
// before any operation that needs persistence (sleep, shutdown).
void nvsFlush() {
  if (nvsDirtyVolume) {
    prefs.putFloat(PREF_VOL, player.getVolume());
    nvsDirtyVolume = false;
  }
  if (nvsDirtyEq) {
    prefs.putUChar(PREF_EQ, (uint8_t)eqMode);
    nvsDirtyEq = false;
  }
  if (nvsDirtyTimer) {
    prefs.putUChar(PREF_TIMER, (uint8_t)timerMode);
    nvsDirtyTimer = false;
  }
  if (nvsDirtyRepeat) {
    prefs.putUChar(PREF_REPEAT, (uint8_t)repeatMode);
    nvsDirtyRepeat = false;
  }
  if (nvsDirtyBookmark) {
    if (player.isAudiobook()) {
      prefs.putString(PREF_BM_PATH, player.currentName());
      prefs.putULong(PREF_BM_POS, (uint32_t)player.getFilePosition());
    }
    nvsDirtyBookmark = false;
  }
  nvsLastDirtyMs = 0;
}

// ── setup ─────────────────────────────────────────────────────────────────────
void setup() {
  // ── Power: disable unused radios and lower CPU clock ──────────────────────
  // WiFi and BT controllers are powered by default; explicitly shut them down.
  // NOTE: do NOT enable automatic light sleep or DFS — both break I2S DMA.
  WiFi.mode(WIFI_OFF);        // ~20–80 mA saving depending on modem idle state
  btStop();                   // de-initialise BT controller
  setCpuFrequencyMhz(240);    // 240→160 MHz: safe for Helix MP3; APLL is independent

  delay(200);  // let USB serial settle

  // Display first so user sees something immediately
  if (!display.begin()) {
    while (true) delay(1000);
  }

  buttons.begin();

  if (!player.begin()) {
    // No SD card or no tracks — show message and poll for recovery.
    display.showTrack("No SD Card", 0, 0, false);
    uint32_t lastSdPoll = millis();
    while (true) {
      buttons.poll();
      if (buttons.sleepRequested()) {
        ESP.restart();
      }
      // Periodically retry SD mount — card may have been inserted.
      if (millis() - lastSdPoll >= 2000) {
        lastSdPoll = millis();
        if (SD.begin(SD_CS, SPI)) {
          ESP.restart();
        }
      }
      delay(10);
    }
  }

  // Restore last volume from NVS, falling back to a conservative default.
  prefs.begin(PREF_NS, false);
  player.setVolume(prefs.getFloat(PREF_VOL, DEFAULT_VOLUME));
  display.showVolume(player.getVolume());  // seed volume state before first draw

  // Restore settings from NVS.
  eqMode     = (EqMode)    prefs.getUChar(PREF_EQ,     (uint8_t)EqMode::FLAT);
  timerMode  = (TimerMode) prefs.getUChar(PREF_TIMER,  (uint8_t)TimerMode::OFF);
  repeatMode = (RepeatMode)prefs.getUChar(PREF_REPEAT, (uint8_t)RepeatMode::ALL);
  player.setEQ(eqMode);
  player.setRepeatMode(repeatMode);
  // Timer resets on every boot — do not restore timerStartMs.

  // Restore audiobook bookmark: if the current track matches the saved bookmark,
  // seek to the saved position so the user resumes where they left off.
  {
    String bmPath = prefs.getString(PREF_BM_PATH, "");
    uint32_t bmPos = prefs.getULong(PREF_BM_POS, 0);
    if (bmPath.length() > 0 && bmPos > 0 && player.currentName() == bmPath) {
      player.seekToPosition(bmPos);
    }
  }

  refreshTrackDisplay();

  if (!accel.begin()) {
  }

  // Configure battery monitor pins.
  // CHG_LBO is open-drain on MCP73871T — INPUT_PULLUP ensures a defined HIGH when battery is OK.
  pinMode(CHG_LBO,        INPUT_PULLUP);
  pinMode(CHG_USB_DETECT, INPUT);
}

// ── loop ──────────────────────────────────────────────────────────────────────
void loop() {
  // ── Low battery: monitor-only mode (replaces all normal operation) ───────────
  // Audio and SPI are already shut down; just refresh the USB indicator.
  // When LBO goes high the battery has recovered — full restart.
  if (lowBattery) {
    if (digitalRead(CHG_LBO) == HIGH || digitalRead(CHG_USB_DETECT) == HIGH) {
      ESP.restart();
    }
    delay(50);
    return;
  }

  buttons.poll();

  // ── LBO transition: battery just went low ─────────────────────────────────
  // Skip if USB is connected — the device can run on USB power while charging.
  if (digitalRead(CHG_LBO) == LOW && digitalRead(CHG_USB_DETECT) == LOW) {
    lowBattery = true;
    saveBookmark();
    nvsFlush();
    player.shutdown();
    display.showLowBattery(false);
    return;
  }

  player.update();   // feeds audio pipeline

  // ── SD card removal detection ──────────────────────────────────────────────
  if (player.sdError()) {
    display.showTrack("SD Removed", 0, 0, false);
    // Poll for SD reinsertion; allow play-hold restart.
    while (true) {
      buttons.poll();
      if (buttons.sleepRequested()) {
        ESP.restart();
      }
      if (SD.begin(SD_CS, SPI)) {
        ESP.restart();
      }
      delay(500);
    }
  }

  // Check if playback stopped at end-of-playlist (RepeatMode::OFF)
  if (player.stoppedAtEnd()) {
    refreshTrackDisplay();
  }

  // ── Sleep timer ────────────────────────────────────────────────────────────
  if (timerMode != TimerMode::OFF && timerStartMs != 0) {
    uint32_t limitMs = (timerMode == TimerMode::MIN30) ? 30UL * 60000 : 60UL * 60000;
    if (millis() - timerStartMs >= limitMs) {
      if (player.isPlaying()) {
        player.togglePause();
        refreshTrackDisplay();
      }
      timerMode  = TimerMode::OFF;
      timerStartMs = 0;
      nvsDirtyTimer  = true;
      nvsLastDirtyMs = millis();
    }
  }

  // ── Button events ───────────────────────────────────────────────────────────
  // Double-tap toggles the settings menu.  play() also fires on the same cycle
  // (immediate dispatch), so check doubleTap first.
  bool dblTap = buttons.doubleTap();
  if (dblTap) {
    if (appState == AppState::PLAYING) {
      appState = AppState::IN_MENU;
      menuItem = 0;
      display.showMenu(menuItem, eqMode, timerMode, repeatMode);
    } else {
      appState = AppState::PLAYING;
      refreshTrackDisplay();
    }
  }

  // Long press on the Back (prev) button opens the playlist navigator.
  if (buttons.prevHeld() && appState == AppState::PLAYING) {
    appState    = AppState::IN_PLAYLIST;
    // Restore selection to the current active playlist.
    const String& active = player.getPlaylistName();
    if (active.isEmpty()) {
      playlistSel = 0;
    } else {
      playlistSel = 0;
      const auto& folders = player.getFolders();
      for (int i = 0; i < (int)folders.size(); i++) {
        if (folders[i] == active) { playlistSel = i + 1; break; }
      }
    }
    display.showPlaylistMenu(playlistSel, player.getFolders());
  }

  // Long press on the Next button opens the chapter navigator (audiobook only).
  if (buttons.nextHeld() && appState == AppState::PLAYING && player.isAudiobook()) {
    appState   = AppState::IN_CHAPTERS;
    chapterSel = max(0, player.getCurrentChapterIndex());
    display.showChapterMenu(chapterSel, player.getChapters());
  }

  if (appState == AppState::IN_MENU) {
    if (buttons.vdown()) {
      menuItem = (menuItem + 1) % 4;
      display.showMenu(menuItem, eqMode, timerMode, repeatMode);
    }
    if (buttons.vup()) {
      menuItem = (menuItem + 3) % 4;  // (i - 1 + 4) % 4
      display.showMenu(menuItem, eqMode, timerMode, repeatMode);
    }
    if (buttons.play()) {
      bool stayInMenu = true;
      switch (menuItem) {
        case 0:  // EQ: cycle Loud → Bass Boost → Flat → Loud
          eqMode = (EqMode)(((int)eqMode + 1) % 3);
          player.setEQ(eqMode);
          nvsDirtyEq     = true;
          nvsLastDirtyMs = millis();
          break;
        case 1:  // Timer: cycle Off → 30 min → 60 min → Off
          timerMode = (TimerMode)(((int)timerMode + 1) % 3);
          timerStartMs = (timerMode != TimerMode::OFF) ? millis() : 0;
          nvsDirtyTimer  = true;
          nvsLastDirtyMs = millis();
          break;
        case 2:  // Repeat: cycle All → One → Off → All
          repeatMode = (RepeatMode)(((int)repeatMode + 1) % 3);
          player.setRepeatMode(repeatMode);
          nvsDirtyRepeat = true;
          nvsLastDirtyMs = millis();
          break;
        case 3:  // Exit
          appState = AppState::PLAYING;
          refreshTrackDisplay();
          stayInMenu = false;
          break;
      }
      if (stayInMenu) {
        display.showMenu(menuItem, eqMode, timerMode, repeatMode);
      }
    }
  } else if (appState == AppState::IN_PLAYLIST) {
    int totalItems = 1 + (int)player.getFolders().size();
    if (buttons.vdown()) {
      playlistSel = min(playlistSel + 1, totalItems - 1);
      display.showPlaylistMenu(playlistSel, player.getFolders());
    }
    if (buttons.vup()) {
      playlistSel = max(playlistSel - 1, 0);
      display.showPlaylistMenu(playlistSel, player.getFolders());
    }
    if (buttons.play()) {
      // Confirm selection: switch playlist and return to playing screen.
      saveBookmark();  // persist audiobook position before changing playlist
      if (playlistSel == 0) {
        player.setPlaylist("");  // All Songs
      } else {
        player.setPlaylist(player.getFolders()[playlistSel - 1]);
      }
      appState = AppState::PLAYING;
      refreshTrackDisplay();
    }
    if (buttons.prev()) {
      // Back out without changing the active playlist.
      appState = AppState::PLAYING;
      refreshTrackDisplay();
    }
  } else if (appState == AppState::IN_CHAPTERS) {
    int totalChapters = (int)player.getChapters().size();
    if (buttons.vdown()) {
      chapterSel = min(chapterSel + 1, totalChapters - 1);
      display.showChapterMenu(chapterSel, player.getChapters());
    }
    if (buttons.vup()) {
      chapterSel = max(chapterSel - 1, 0);
      display.showChapterMenu(chapterSel, player.getChapters());
    }
    if (buttons.play()) {
      player.seekToChapter(chapterSel);
      appState = AppState::PLAYING;
      refreshTrackDisplay();
    }
    if (buttons.next() || buttons.prev()) {
      // Back out without seeking.
      appState = AppState::PLAYING;
      refreshTrackDisplay();
    }
  } else {

    if (buttons.next()) {
      saveBookmark();
      player.next();
      refreshTrackDisplay();
    }

    if (buttons.prev()) {
      saveBookmark();
      player.prev();
      refreshTrackDisplay();
    }

    // In PLAYING state, play() fires immediately on tap release.  Skip if
    // doubleTap already consumed this press (menu toggle takes priority).
    if (!dblTap && buttons.play()) {
      if (player.isPlaying()) saveBookmark();  // save before pausing
      player.togglePause();
      refreshTrackDisplay();
    }
  }

  if (buttons.sleepRequested()) {
    saveBookmark();  // mark bookmark dirty
    nvsFlush();      // flush all pending NVS writes before sleep
    // Show farewell message, blank display, then enter deepest sleep that
    // can still be woken by the play button (EXT1 on RTC GPIO, active LOW).
    display.showPowerOff();
    delay(1500);
    display.turnOff();
    rtc_gpio_pullup_en((gpio_num_t)BTN_PLAY);
    rtc_gpio_pulldown_dis((gpio_num_t)BTN_PLAY);
    esp_sleep_enable_ext1_wakeup(1ULL << BTN_PLAY, ESP_EXT1_WAKEUP_ANY_LOW);
    esp_deep_sleep_start();
    // Wake from deep sleep triggers a full restart — setup() runs again.
  }

  if (appState == AppState::PLAYING) {
    if (buttons.vup()) {
      adjustVolume(+VOL_STEP);
    }
    if (buttons.vdown()) {
      adjustVolume(-VOL_STEP);
    }
  }

  // ── Scroll animation — skip while display sleep or menu is active ─────────────
  if (!displaySleeping && appState == AppState::PLAYING) {
    display.update();
  }

  // ── Chapter boundary tracking (audiobook only) ─────────────────────────────
  if (appState == AppState::PLAYING && player.isAudiobook() && player.isPlaying()) {
    uint32_t now = millis();
    if (now - lastChapterCheckMs >= CHAPTER_CHECK_MS) {
      lastChapterCheckMs = now;
      int ch = player.getCurrentChapterIndex();
      if (ch >= 0 && ch != lastChapterIdx) {
        lastChapterIdx = ch;
        refreshTrackDisplay();
      }
    }
  }

  // ── Display sleep (accelerometer 6D orientation) ───────────────────────────
  // Sleep: hardware interrupt fires after device is flat for 2 s.
  if (!displaySleeping && accel.consumeFlatEvent()) {
    refreshTrackDisplay();       // pre-draw track screen into OLED RAM
    display.turnOff();           // clear + DISPLAYOFF
    displaySleeping = true;
  }

  // Wake: poll orientation every 100 ms; turn on as soon as device is raised.
  if (displaySleeping) {
    uint32_t now = millis();
    if (now - lastOrientPollMs >= ORIENT_POLL_MS) {
      lastOrientPollMs = now;
      if (!accel.isFlat()) {
        accel.clearFlatEvent();  // discard any queued flat event from while sleeping
        if (appState == AppState::IN_MENU) {
          display.showMenu(menuItem, eqMode, timerMode, repeatMode);
        } else if (appState == AppState::IN_PLAYLIST) {
          display.showPlaylistMenu(playlistSel, player.getFolders());
        } else if (appState == AppState::IN_CHAPTERS) {
          display.showChapterMenu(chapterSel, player.getChapters());
        } else {
          refreshTrackDisplay();   // draw content before DISPLAYON to avoid blank flash
        }
        display.turnOn();
        displaySleeping = false;
      }
    }
  }

  // ── Deferred NVS flush ─────────────────────────────────────────────────────
  if (nvsLastDirtyMs != 0 && (millis() - nvsLastDirtyMs) >= NVS_FLUSH_DELAY_MS) {
    nvsFlush();
  }
}

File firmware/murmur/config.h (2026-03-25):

#pragma once

// ── I2S / DAC ─────────────────────────────────────────────────────────────────
#define I2S_DOUT       12
#define I2S_FSYNC      13
#define I2S_BCLK       14

// ── SD Card ───────────────────────────────────────────────────────────────────
#define SD_MISO        16
#define SD_MOSI        18
#define SD_SCK         17
#define SD_CS           8

// ── I2C / Display ─────────────────────────────────────────────────────────────
#define SDA_PIN         9
#define SCL_PIN        10
#define OLED_ADDR      0x3C
#define SCREEN_WIDTH   128
#define SCREEN_HEIGHT   64

// ── Buttons ───────────────────────────────────────────────────────────────────
#define BTN_NEXT        4
#define BTN_PREV        7
#define BTN_VUP         6
#define BTN_VDOWN      15
#define BTN_PLAY        5

// ── Charge management ─────────────────────────────────────────────────────────
#define CHG_USB_DETECT 38  // HIGH when USB power is present
#define CHG_STAT2      41
#define CHG_STAT1      42
// LBO (Low Battery Output) of MCP73871T is open-drain, routed to GPIO42.
// Goes LOW when V_BAT < 3.1 V; recovers HIGH after V_BAT > 3.25 V (hysteresis).
// Configure as INPUT_PULLUP on the ESP32.
#define CHG_LBO        42

// ── LIS3DH Accelerometer ──────────────────────────────────────────────────────
#define LIS3DH_ADDR    0x19   // SA0 pulled to GND via 100kΩ, but LIS3DH internal pull-up dominates → SA0 high
#define LIS3DH_INT1    40
#define LIS3DH_INT2    39

// ── App settings enums ────────────────────────────────────────────────────────
enum class EqMode     : uint8_t { LOUD = 0, BASS_BOOST, FLAT };
enum class TimerMode  : uint8_t { OFF  = 0, MIN30, MIN60 };
enum class RepeatMode : uint8_t { ALL  = 0, ONE, OFF };
